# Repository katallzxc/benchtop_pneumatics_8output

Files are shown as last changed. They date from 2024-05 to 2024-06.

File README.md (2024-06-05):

# Benchtop pneumatic actuation apparatus with 8 output channels
## Hatton Lab @ the University of Toronto

This repository documents the benchtop pneumatic actuation system used in the Hatton Lab (Bio-Inspired Materials and Design Laboratory) at the University of Toronto.

The benchtop pneumatics system has been recently updated. Previous versions of the system are documented in another repository (https://github.com/sitruklaq/Hattonlab-Pneumatics).

## Repository structure
 - The **documentation** folder is currently largely empty but will contain general documentation for the system (i.e., code logic flow, list of serial commands, etc.).
 - The **components** folder is currently largely empty but will contain a list of all components bought for the system (excluding components that were fabricated in-house) and datasheets for the individual components.
 - The **code** folder contains both (1) Arduino code sketches that can be uploaded to the microcontroller to test system function or run the actuation control loop and (2) a copy of the serial code (in Python) used to send serial commands to the microcontroller from a PC.
 - The **circuits** folder is currently largely empty but will contain a circuit diagram for the system as well as circuit diagrams for subcomponents.
 - The **CAD** folder is currently largely empty but will contain copies of the CAD models for structural elements of the system.

## Quick-start user guide
(to be filled)

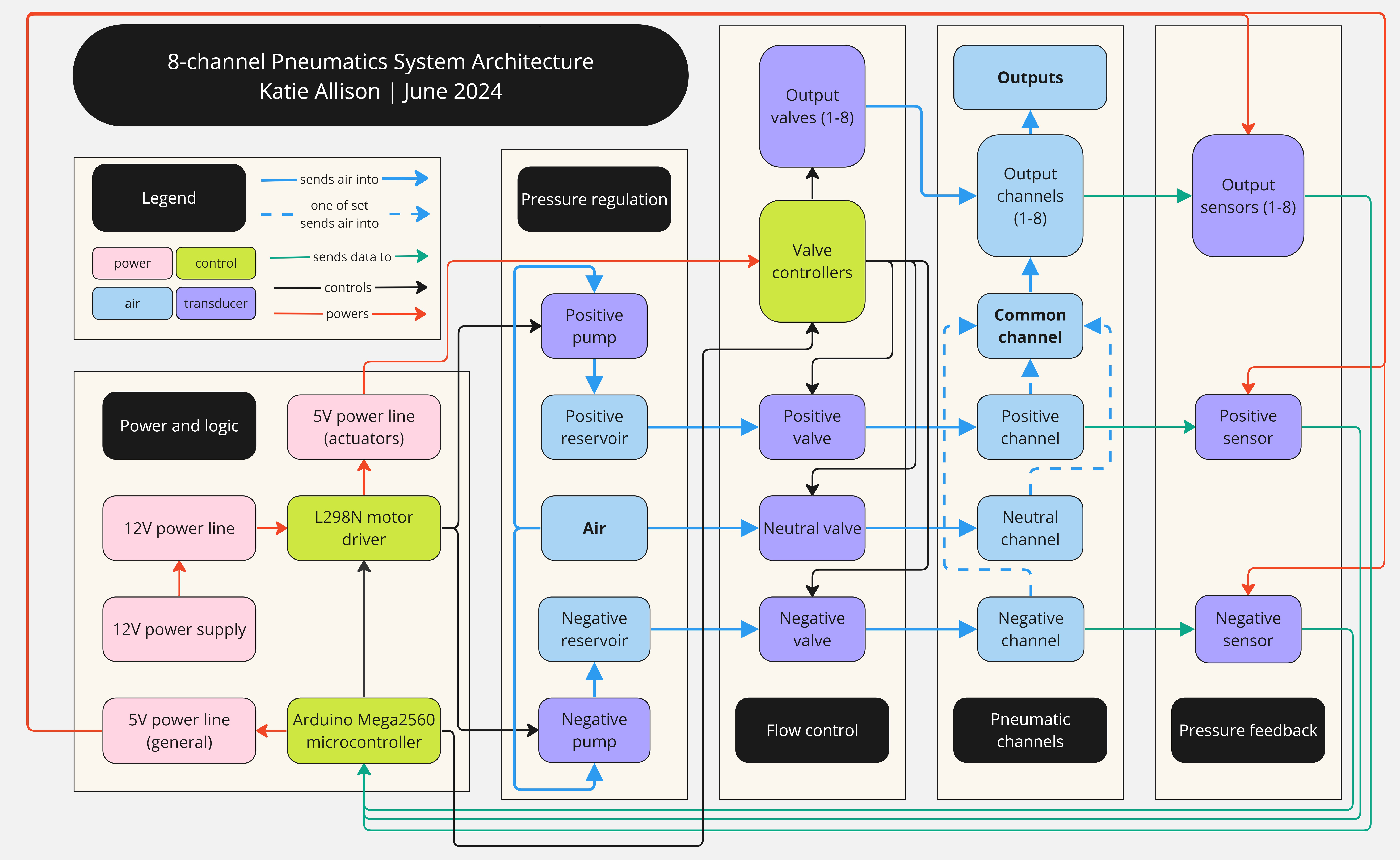
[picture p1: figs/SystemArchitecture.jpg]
SystemArchitecture


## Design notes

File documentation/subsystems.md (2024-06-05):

# Apparatus Description

The multi-channel pneumatics system maintains three reference pressure levels (usually, positive, negative, and neutral) as inputs and allows up to eight output lines to be pressurized using a reference pressure level and the common line that connects inputs and outputs. Each of the three input lines can be opened or closed to connect them to or disconnect them from the common line.

The neutral pressure level is open to the atmosphere and hence always maintains a pressure of 0 kPa relative to environmental conditions. The positive and negative pressure levels, conversely, are pressurized by using pumps to transfer air into or out of air reservoirs, raising or lowering the internal reservoir pressure.

The workflow to actuate a pneumatic device as an output is as follows:

1. Begin with all input and output valves closed so that nothing is connected to the shared line.
2. Set the input connection to either the negative input (if the desired output pressure is below 0 kPa) or the positive input (if the desired output pressure is above 0 kPa).
3. Run the pump for the selected input line until the air reservoir contains air at the desired output pressure.
4. Open the valve connecting the shared line to the neutral pressure level to neutralize the shared line.
5. Close the valve between the neutral pressure level and the shared line, disconnecting the shared line from the environmental pressure conditions.
6. Open the valve connecting the shared line to the selected input line to bring the shared line to the desired output pressure.
7. Once pressure in the shared line has reached the desired output pressure, open the valve connecting the shared line to the desired output device.
8. Keeping the selected input line and the desired output line open to the shared line, run the pump for the selected input line as needed to regulate the pressure in the system.

The pneumatics system can be divided into four main subsystems:

1. Pressure regulation subsystem
2. Valve subsystem
3. Pressure sensor subsystem
4. Structural subsystem

The first subsystem, pressure regulation, uses only the input pressure lines. The other subsystems relate to both inputs and outputs.

## Pressure regulation subsystem

The pressure regulation subsystem maintains pressure setpoints in the positive and negative input air reservoirs. This subsystem involves multiple components:

1. The **air reservoirs** hold air and are used to maintain a reservoir of air pressurized to a set level. The two reservoirs in this system are designated as “positive” and “negative”.
2. The **air pumps** move air into or out of the air reservoirs.
3. The **motor driver** controls the power at which the pumps operate and sends driving signals to the pumps.
4. The **Arduino microcontroller** sends control signals to the driver turn the pumps on or off and to change the power at which the pumps operate. 

## Valve subsystem

The valve subsystem consists of the 11 valves (3 input, 8 output) used to control connections between the input/output channels and the common channel, as well as the Arduino microcontroller board used to control these valves and a 5V power input.

The valves are 2-way solenoid valves (RLM204P30B, Asco) and normally closed (meaning that they are closed at 0 VDC and open at 5 VDC). The control circuit for the valves uses NPN transistors (SS8050, Fairchild Semiconductor Corporation) to direct a 5V input flow to or away from the valves based on a logic signal from the Arduino microcontroller board.

An example of a PCB layout for one of the valve circuits made by Kurtis Laqua is shown below.

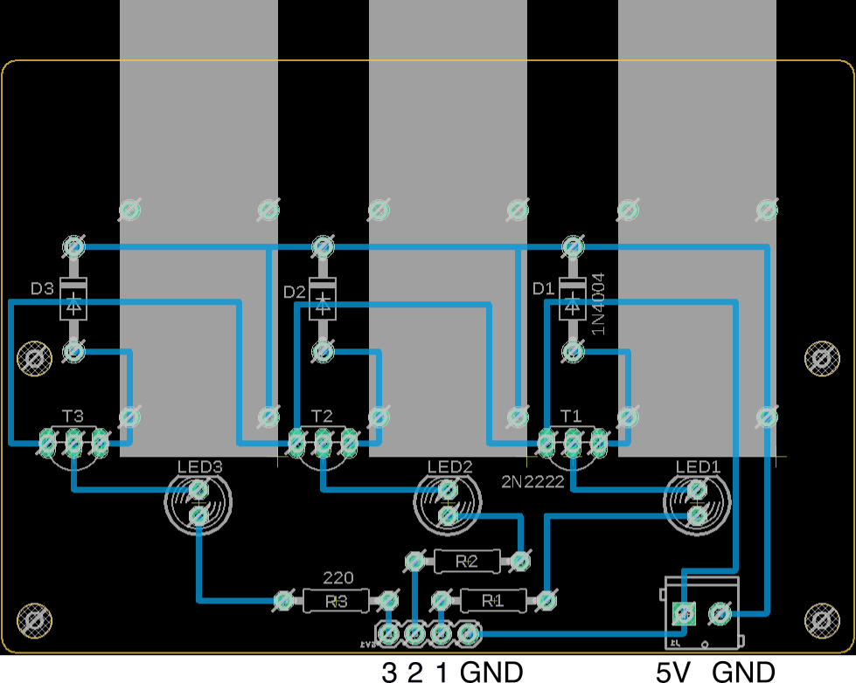
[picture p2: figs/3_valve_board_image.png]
InputValvePCB


#TODO: confirm 5V from L298N onboard regulator & fill out here

## Pressure sensor subsystem

The pressure sensor subsystem consists of the 10 sensors (2 input, 8 output) used to read pressure levels in the positive input, negative input, and output channels and the common channel, as well as the Arduino microcontroller board used to take these readings.

The sensors (ADP5101, Panasonic) have a range of +/-100 kPa and are active sensors (meaning that they require a voltage input, which in this case is 5 VDC). The control circuit for the sensors connects the 5V output from the Arduino microcontroller board to the sensor power input and connects the Arduino input pin to the sensor data output.

An example of a PCB layout for one of the pressure sensor circuits made by Kurtis Laqua is shown below.

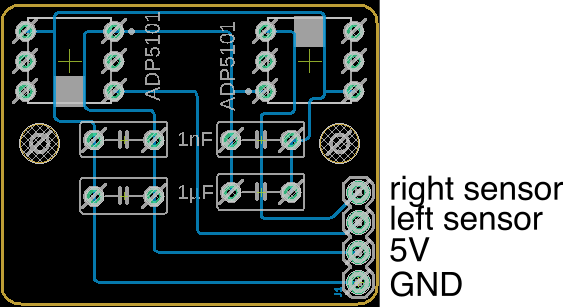
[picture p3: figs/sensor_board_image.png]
SensorPCB


## Structural subsystem

The structural subsystem consists of pneumatic and mechanical connectors. Pneumatic connectors include tubes and luer fittings connecting the input pumps and output connectors to the shared channel. Mechanical connectors mainly consist of bolts and standoffs used to connect components and circuits to sheets of acrylic, with the base sheet holding the pumps and reservoirs, a sheet above the pumps and reservoirs holding the majority of the remaining components, and a few small raised platforms holding power switches and connectors.

# System Architecture

The following image shows an alternate, more granular system architecture.

SystemArchitecture

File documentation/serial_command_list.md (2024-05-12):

# Serial commands for pneumatics apparatus

## Communication protocol

### Component indices
Individual components are referenced in commands by integer IDs that reference the index of the component within an enum variable assignment. Component indices are assigned as follows:

**Pumps**:
0. NEG
1. POS

**Input valves**:
0. NEG
1. NEU
2. POS

**Input pressure sensors**:
0. NEG
1. NEU
2. POS

**Output valves**:
Integers in the 0-7 range used (in order) as indices for outputs 1-8

**Output pressure sensors**:
Integers in the 0-7 range used (in order) as indices for outputs 1-8

### Component states and setpoints
Actuator components (pumps or valves) have associated binary states.

For pumps, the states are:
0. OFF
1. ON

For valves, the states are:
0. CLOSED
1. OPEN

Pumps take a *setpoint* value in addition to the aforementioned state value. The setpoint defines the pressure that a specific input channel should maintain. For instance, the NEG pump might receive a setpoint of -40 kPa--in this case, the pump will turn ON when the NEG pressure sensor value (reading the pressure in the NEG input channel) is greater than -40 kPa. The pump will turn OFF once the NEG pressure sensor value falls to or below -40 kPa.

### Command string format
All commands are provided in a string with "<" as the start marker character and ">" as the end marker character. Each command consists of three parts separated by a comma and space (", "):
1. Command string (two letters)
2. Component index (integer)
3. State or setpoint (integer)
If any of this three parts are not applicable to a specific command (e.g., if using a command that applies to *all* input/output elements, where a component index is not necessary), the default value 999 should be used.

## Command list
| Command | Format | Action |
| --- | --- | --- |
| SI | <SI, valve #, valve state> | Sets the state of a single input valve. |
| SO | <SO, valve #, valve state> | Sets the state of a single output valve. |
| AI | <AI, 999, valve state> | Sets the state of all input valves. |
| AO | <AO, 999, valve state> | Sets the state of all output valves. |
| GI | <GI, sensor #, 999> | Returns ("gets") the pressure sensor reading for a single input channel. |
| GO | <GO, sensor #, 999> | Returns ("gets") the pressure sensor reading for a single output channel. |
| VI | <VI, valve #, 999> | Returns the current state of a single input valve. |
| VO | <VO, valve #, 999> | Returns the current state of a single output valve. |
| RS | <RS, pump #, pump setpoint> | Sets the setpoint for a single pump (and hence for the corresponding input channel). |
| RG | <RG, pump #, 999> | Returns the current setpoint for a single pump. |
| PS | <PS, pump #, pump state> | Sets the state of a single pump. |
| PG | <PG, pump #, 999> | Returns the current state of a single pump. |

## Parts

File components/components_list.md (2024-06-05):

| Component | Supplier  | Model | Cost  | Quantity  | Total Cost | Description |
| --- | ---  | ----- | ----- | ---  | --- | --- |
| Microcontroller | Elegoo (Amazon)| ATMega2560|19.99|1|19.99| Arduino-like microcontroller|
| Pneumatic pumps | Creatron|D2028|27.95|1|55.90|Vacuum pumps with 12V operating voltage|
|Pneumatic valves |Asco (Jameco)|RLB204KP30B|6.95 USD|11|76.45 USD|2-way solenoid valves with 5V operating voltage|
|Pressure sensors |Panasonic (Mouser)|ADP5101|60.00|7|420.00|DIP-mount pressure sensors with range of +/-100 kPa and 5V operating voltage|
| | | | | 1 | | |
| | | | | 1 | | |
| | | | | 1 | | |

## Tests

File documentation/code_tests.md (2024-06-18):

# Summary of Arduino sketches for testing system

## List of test code

The table below lists test sketches in recommended execution order, starting from the most simple/baseline tests and progressing to the most complex tests.

| Directory | Purpose |
|---|---|
|test_pump_actuation | Verify that actuation signals can turn pumps on and off and check that pumps are being actuated in intended order. |
|test_valve_open | Verify that actuation signals can open valves and check that valves are being opened in intended order. |
|test_pressure_sensing | Verify that pressure sensor signals (for input channels only) can be read. With input channels opened (via valve control) to atmospheric pressure, verify that pressure sensor signals are near zero. |
|test_pump_control | Test pump and sensor integration using hardcoded setpoints. Verify that each pump will turn on whenever the input pressure in the corresponding channel is far from the setpoint and then turn off whenever the input pressure reaches the setpoint. |
|test_valve_actuation | Verify that actuation signals can actuate (open **and** close) valves and check that valves are being actuated in intended order. |
|test_integration | Test integrated pump, valve, and sensor system using hardcoded setpoints. Runs a loop of continuous pressure regulation to keep both positive and negative channels at setpoint pressure levels while querying user for valve IDs. Whenever user supplies a valve ID, toggles the state of that valve (from open to closed or from closed to open). Possible valve IDs are positive, negative, and output 0. |

## Description of test code functionality

### Pump actuation testing
This stage of testing verifies that an assembled pump control circuit correctly actuates pumps based on supplied pump ID, state (on/off), and power level.

> [!CAUTION]
> Before using this code, ensure that the pump circuit is correct. Pumps can be proxied with standard DC motors provided that the voltage supply levels for the motors are respected (i.e., if using a 5V motor as a proxy for a 12V pump, ensure that input power is limited to 5V). Ensure that the motor power is not supplied by the microcontroller and that there is protective circuitry (e.g., a motor driver board, or an H-bridge circuit with protective components like diodes) between the pump/motor and the microcontroller.

A sample motor circuit using the L298N motor driver is shown in the image below.

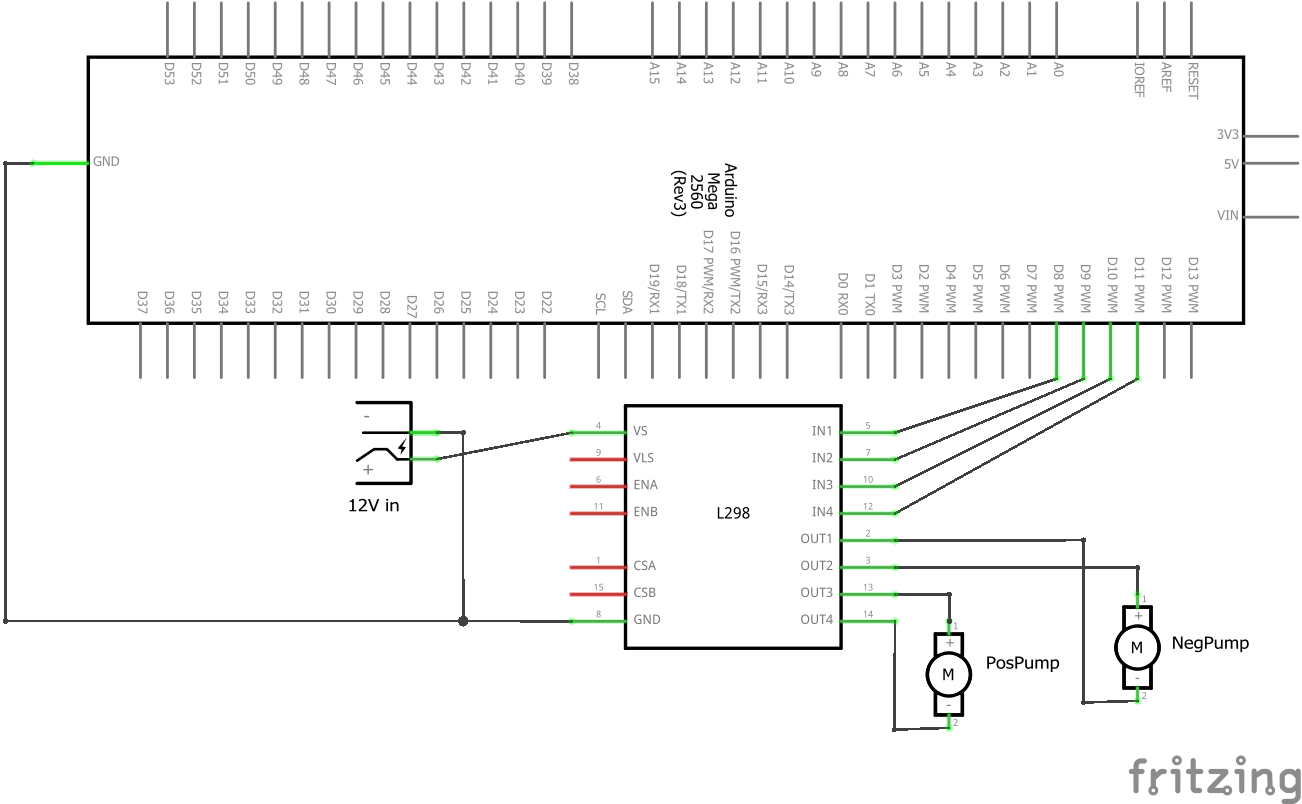
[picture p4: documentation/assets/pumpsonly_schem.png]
PumpCircuit
.

The following **setup** variables must be set or checked:
 - positive input channel pump pins: set the pin numbers for the two Arduino pins used to drive the positive input channel pump
 - negative input channel pump pins: set the pin numbers for the two Arduino pins used to drive the negative input channel pump

For each pump, the microcontroller will send a PWM signal (alternating logic high and logic low) over one pin and set the other pin to logic low. The pump rotation direction depends on which of its leads receives the PWM signal.

> [!NOTE]
> Since the directions of rotation for the pumps do not change (and so the lead that receives the PWM signal is the same every time for each pump), the circuit could alternatively be structured such that one of the leads for each pump is connected to the driver circuit and the other lead is connected directly to ground.

The following **testing** variable must then be set or checked:
 - pump power is set via the `pump_dutycycle` variable to a value between 0 and 255, with a higher duty cycle corresponding to a faster pump speed.

At this stage, the code can be uploaded to the Arduino. You should see the positive pump run for one second, then the negative pump runs for one second, and then both pumps run simultaneously for one second, after which the loop repeats.

> [!TIP]
> Since it is difficult to tell whether the pumps are turning in the correct directions given their corresponding input channel (i.e., positive pump should move air into the reservoir and negative pump should move air out), it's best to also try the `test_pump_control` test once the pressure sensors have been integrated and are functional.

### Valve opening testing
This stage of testing verifies that an assembled valve circuit with 3 input valves and 8 output valves can open all valves in order.

> [!CAUTION]
> Before using this code, ensure that the valve circuit is correct. The solenoid valves in this circuit can be proxied with standard solenoids that operate at 5V. Ensure that the valve power is not supplied by the microcontroller and that there is protective circuitry (e.g., a transistor circuit with protective components like diodes) between the valve and the microcontroller.

The PCB layout for the 3 input valves is shown in the image below. This tester code assumes that the 3-input valve board is used to control input valves and two 4-input valve boards are used to control output valves.

> [!NOTE]
> This PCB layout appears to have labelled the 5V and GND connections incorrectly (swapping their labels) so interpret it carefully with this mistake in mind to correctly identify connections.

ValveCircuit.

The following **setup** variables must be set or checked:
 - input valve pins: set the pin numbers for the three Arduino pins used to drive the input valves. The pins used are [53, 52, 51], corresponding to the positive, negative, and neutral valves respectively.
 - output valve pins: set the pin numbers for the three Arduino pins used to drive the input valves. The pins used are [47,46,45,44,31,30,29,28], corresponding to the valves for output channels 0 to 7 in order.

At this stage, the code can be uploaded to the Arduino. For each valve, the microcontroller will set the corresponding pin to logic high, whereupon the valve should open.

> [!TIP]
> If the PCBs are not available, transistor circuits can be constructed to switch valve state (see this Sparkfun tutorial for a good explanation SparkFunTransistorSwitch). Alternatively, if you wish to quickly check whether the valves open but do not need to open them in order, you can skip the microcontroller connection entirely and simply apply 5V to the leads of a valve directly.

### Pressure sensing testing
This stage of testing verifies that an assembled pressure sensor circuit correctly reads and calibrates sensor values. Calibration is checked by taking pressure sensor readings for each channel with the channel valve open to atmospheric pressure. Since the pressure in the channel should be equalized to environmental conditions when the channel is open to the atmosphere, the pressure reading should hence be equal to approximately 0.

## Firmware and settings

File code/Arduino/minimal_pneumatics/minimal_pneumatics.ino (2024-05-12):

/* Minimal Pneumatics
    for pneumatic device control using multichannel pneumatic setup in the Hatton lab
    Katie Allison, 2024;
        see 
    Loosely based off code by Kurtis Laqua; 
        see https://github.com/sitruklaq/Hattonlab-Pneumatics/tree/master/Arduino%20Code
*/
#include "minimal_pneumatics.h"

// set pump duty cycle (i.e., how hard air is pumped)
int pump_duty_cycle = 190;

// set values of buffers and delays
float pumpSetpointBuffer = 0.3; // in kPa
int pressureSwitchDelay = 25; // in ms?

// initialize pump control variables (for getting current pressure and updating pump state)
float updated_pressure_val;
float neg_pressure_setpoint = 0;
float pos_pressure_setpoint = 0;
float neg_pressure_running_avg;
float pos_pressure_running_avg;
int updated_pump_state;

void setup() {
    initialize_pins();
    Serial.begin(19200);
}

void loop() { 
    // receive and act on any serial inputs
    recv_serial_command();
    if (newSerialInputReady) {
        parse_command_data();
        act_on_command();   // based on input command, open/close valves or change pump setpoints
    }
    // regulate input channel pressures to current setpoints
    pressure_control(pump_duty_cycle);
}

//---THIS FUNCTION IS THE MAIN CONTROL LOOP
void pressure_control(int pump_dutycycle) {
    // get pressure sensor readings (calibrated to kPa) and update running averages
    read_pressure_sensors();
    for (int i = 0; i < NUM_IN_SENSORS ; i++) {
        updated_pressure_val = inputPressureValsCurrent[i];
        inputPressureValsAverage[i] = (inputPressureValsAverage[i] + 99.f*updated_pressure_val)/100.f;
    }
    for (int i = 0; i < NUM_OUT_SENSORS ; i++) {
        updated_pressure_val = outputPressureValsCurrent[i];
        outputPressureValsAverage[i] = (outputPressureValsAverage[i] + 99.f*updated_pressure_val)/100.f;
    }

    // control negative reservoir pump state based on average negative input channel pressure values
    neg_pressure_running_avg = inputPressureValsAverage[input_sensors::INS_NEG];
    neg_pressure_setpoint = pumpSetpoints[pumps::NEG];
    if (neg_pressure_running_avg > (neg_pressure_setpoint + pumpSetpointBuffer)) {
        updated_pump_state = PUMP_ON;
    }
    else if (neg_pressure_running_avg < (neg_pressure_setpoint - pumpSetpointBuffer)){
        updated_pump_state = PUMP_OFF;
    }
    else{
        //Serial.println("INFO: Negative pump in buffer range of setpoint");
    }
    set_pump_state(pumps::NEG,updated_pump_state,pump_dutycycle);

    // control positive reservoir pump state based on average positive input channel pressure values
    pos_pressure_running_avg = inputPressureValsAverage[input_sensors::INS_POS];
    pos_pressure_setpoint = pumpSetpoints[pumps::POS];
    if (pos_pressure_running_avg < (pos_pressure_setpoint - pumpSetpointBuffer)) {
        updated_pump_state = PUMP_ON;
    }
    else if (pos_pressure_running_avg > (pos_pressure_setpoint + pumpSetpointBuffer)){
        updated_pump_state = PUMP_OFF;
    }
    else{
        //Serial.println("INFO: Positive pump in buffer range of setpoint");
    }
    set_pump_state(pumps::POS,updated_pump_state,pump_dutycycle);
}
//-----------------------

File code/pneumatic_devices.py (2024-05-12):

''' PNEUMATIC_DEVICES v1.0 - Katherine Allison

Created: 2024-02-15
Updated: 2024-02-18

Defines object for pneumatic device control communication.
'''
import serial
import time

class PneumaticConnection:
    TERMINATOR = '\r'.encode('UTF8')
    FILLER_STRING = 99
    
    def __init__(self, device='COM7', baud=19200, timeout=1):
        self.serial = serial.Serial(device, baud, timeout=timeout)
        self.pos_string = "POS"
        self.neg_string = "NEG"
        self.neu_string = "NEU"
        self.input_strings = [self.pos_string,self.neg_string,self.neu_string]
        self.base_out_string = "OUT"
        self.ON,self.OFF = True,False
        self.OPEN,self.CLOSED = True,False

    def set_indices(self,valves,sensors,pumps):
        self.valves = valves
        self.sensors = sensors
        self.pumps = pumps

    def assemble_command(self,command_code, id=None, val=None,print_command=False):
        if not (isinstance(val,int) or isinstance(id,int)):
            print("Incorrect serial command call for pneumatics")
            raise TypeError
        elif not isinstance(id,int):
            id = PneumaticConnection.FILLER_STRING
        elif not isinstance(val,int):
            val = PneumaticConnection.FILLER_STRING
        command_string = '<{0},{1},{2}>'.format(command_code,id,val)
        if print_command: print(command_string)
        return command_string 

    def receive(self) -> str:
        line = self.serial.read_until(self.TERMINATOR)
        return line.decode('UTF8').strip()

    def send(self, text:str) -> bool:
        line = '%s\n'%(text)
        self.serial.write(line.encode('UTF8'))
        echo = self.receive()
        return text == echo
    
    def set_single_valve(self,valve_string,valve_state):
        # define serial commands and get command string
        SET_SINGLE_IN_VALVE = "SI"  # command format: <SI, valve #, valve state>
        SET_SINGLE_OUT_VALVE = "SO" # command format: <SO, valve #, valve state>
        if valve_string in self.input_strings:
            command_str = SET_SINGLE_IN_VALVE
        else:
            command_str = SET_SINGLE_OUT_VALVE

        # send serial command
        valve_id = self.valves[valve_string]
        full_command = self.assemble_command(command_str,id=valve_id,val=valve_state)
        self.send(full_command)
    
    def set_valve_group(self,use_inputs,valve_state):
        # define serial commands and get command string
        SET_ALL_IN_VALVES = "AI"    # command format: <AI, 999, valve state>
        SET_ALL_OUT_VALVES = "AO"   # command format: <AO, 999, valve state>
        if use_inputs:
            command_str = SET_ALL_IN_VALVES
        else:
            command_str = SET_ALL_OUT_VALVES

        # send serial command
        full_command = self.assemble_command(command_str,val=valve_state)
        self.send(full_command)

    def get_valve_state(self,valve_string):
        # define serial commands and get command string
        GET_IN_VALVE_STATE = "VI"  # command format: <VI, valve #, 999>
        GET_OUT_VALVE_STATE = "VO" # command format: <VO, valve #, 999>
        if valve_string in self.input_strings:
            command_str = GET_IN_VALVE_STATE
        else:
            command_str = GET_OUT_VALVE_STATE

        # send serial command
        valve_id = self.valves[valve_string]
        full_command = self.assemble_command(command_str,id=valve_id)
        self.send(full_command)

    def get_pressure_value(self,sensor_string):
        # define serial commands and get command string
        GET_IN_PRESSURE = "GI"      # command format: <GI, sensor #, 999>
        GET_OUT_PRESSURE = "GO"     # command format: <GO, sensor #, 999>
        if sensor_string in self.input_strings:
            command_str = GET_IN_PRESSURE
        else:
            command_str = GET_OUT_PRESSURE

        # send serial command
        sensor_id = self.sensors[sensor_string]
        full_command = self.assemble_command(command_str,id=sensor_id)
        self.send(full_command)
        return self.receive()
    
    def set_reference_setpoint(self,pump_string,pump_setpt):
        # define serial commands and get command string
        SET_REF_SETPOINT = "RS"    # command format: <RS, pump #, pump setpoint>
        command_str = SET_REF_SETPOINT
        pump_id = self.pumps[pump_string]

        # send serial command
        full_command = self.assemble_command(command_str,id=pump_id,val=pump_setpt)
        self.send(full_command)
    
    def get_reference_setpoint(self,pump_string,pump_setpt):
        # define serial commands and get command string
        GET_REF_SETPOINT = "RG"    # command format: <RG, pump #, 999>
        command_str = GET_REF_SETPOINT
        pump_id = self.pumps[pump_string]

        # send serial command
        full_command = self.assemble_command(command_str,id=pump_id)
        self.send(full_command)
    
    def set_pump_state(self,pump_string,pump_state):
        # define serial commands and get command string
        SET_PUMP_STATE = "PS"    # command format: <PS, pump #, pump state>
        command_str = SET_PUMP_STATE
        pump_id = self.pumps[pump_string]

        # send serial command
        full_command = self.assemble_command(command_str,id=pump_id,val=pump_state)
        self.send(full_command)
    
    def get_pump_state(self,pump_string):
        # define serial commands and get command string
        GET_PUMP_STATE = "PG"    # command format: <PG, pump #, 999>
        command_str = GET_PUMP_STATE
        pump_id = self.pumps[pump_string]

        # send serial command
        full_command = self.assemble_command(command_str,id=pump_id)
        self.send(full_command)
    
    def get_pump_pressures(self,print_vals=False):
        neg_pump_pressure = self.get_pressure_value(self.neg_string)
        pos_pump_pressure = self.get_pressure_value(self.pos_string)
        if print_vals:
            print("Positive pump pressure: {0}\nNegative pump pressure: {1}".format(neg_pump_pressure,pos_pump_pressure))
        return [neg_pump_pressure,pos_pump_pressure]

    def switch_input_channel(self,valve_string,delay_time=5):
        # close all input valves then perform neutral evacuation
        self.set_valve_group(True, self.CLOSED)
        self.set_single_valve(self.neu_string, self.OPEN)
        time.sleep(delay_time)

        # open desired input valve
        self.set_single_valve(self.neu_string, self.CLOSED)
        if valve_string in self.input_strings:
            self.set_single_valve(valve_string, self.OPEN)
        else:
            print("Input channel switch routine called on non-input valve!")
            raise ValueError
    
    def test_connection(self,test_string,verbose=True):
        sent_successfully = self.send(test_string)
        if (not sent_successfully and verbose):
            print("Warning: sending data to Arduino microcontroller over serial appears to be broken")
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

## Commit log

2024-06-04 add documentation for pump actuation test
2024-06-04 add sample circuit diagram
2024-06-18 add updated pump test circuit diagram & description of valve test
